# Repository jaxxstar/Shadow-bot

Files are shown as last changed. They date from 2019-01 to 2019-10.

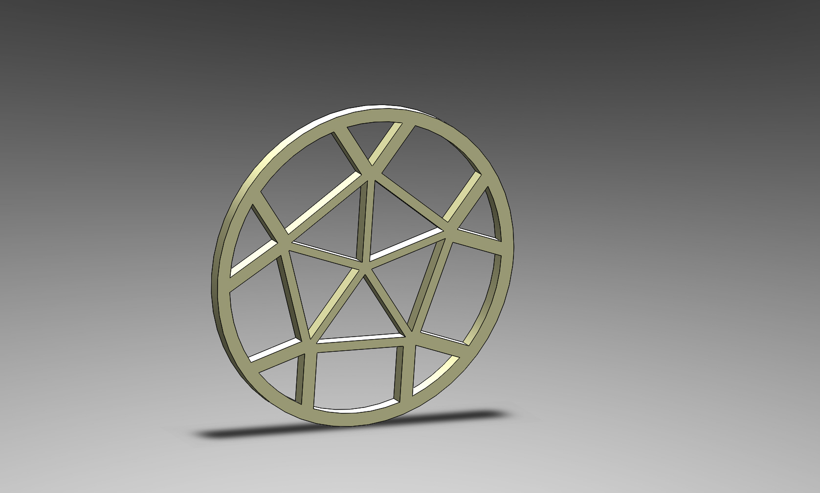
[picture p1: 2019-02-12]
Sangam_Wheel.JPG

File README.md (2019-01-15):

# Shadow Bot

  - Shadow Bot is an all terrain surveillance vehicle(ATV) with a unique capability of transitioning from the ground to the wall .
  - The robot has the ability to move on a wall swiftly and with agility.

# Applications :

> Applications range from monitoring perimeters of highly classified and secured areas such as military bases,airports

> Can be deployed in stealth missions in the army for collecting valuable data such as enemy supplies, enemy location in the army.

> Autonomous robots would save valuable lives in the battlefield simply beacause machines don’t get tired

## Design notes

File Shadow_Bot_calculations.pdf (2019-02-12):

## Shadow Bot Calculations

The governing equations are :
Let the Thrust supplied by the EDF be T, and the Weight off the bot be W, then for No Sliding,

and for No Toppling,

where,
x is the point of application of thrust from the rear wheel of the bot, c is the clearance of the bot with the ground.
For the bot to move ,
Motor torque,M required is ,

where,
R = radius of the wheel.

And also the bot should satisfy these conditions while running,

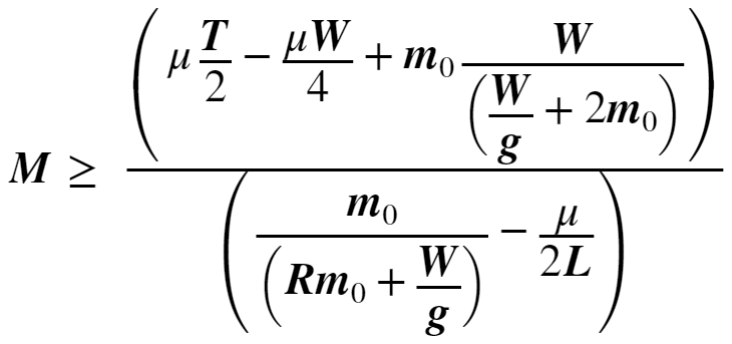
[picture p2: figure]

which has to ensured.
Thrust vs W_max of the bot calculation for different Thrust_distance(x)/clearance of bot ratios keeping other parameters fixed :

% Thrust vs W_max of the bot calculation for different % Thrust_distance(x)/clearance of bot ratios keeping % other parameters fixed
x = table2array(TvsM(13:27,2));
y = table2array(TvsM(13:27,10));
x1 = table2array(TvsM(28:42,2)); y1 = table2array(TvsM(28:42,10)); x2 = table2array(TvsM(43:57,2)); y2 = table2array(TvsM(43:57,10)); x3 = table2array(TvsM(58:72,2)); y3 = table2array(TvsM(58:72,10)); figure;
hold on;
xlabel('Thrust');
ylabel('W-max-toppling');
title('T vs W-max');
plot(x,y,x1,y1,x2,y2,x3,y3);
legend('x/c = 10/8','x/c = 10/7','x/c = 10/6','x/c = 10/5'); grid on;
hold off;

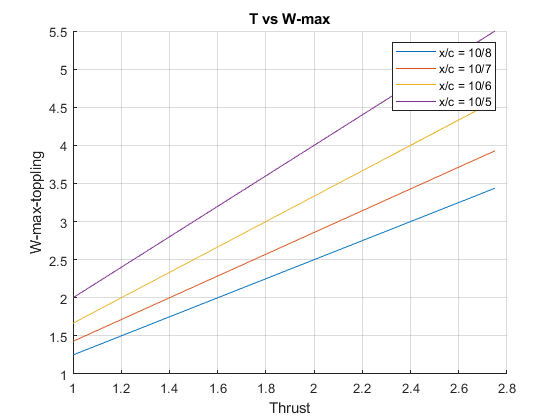
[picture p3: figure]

Motor Torque vs Thrust for the same above conditions :

% Motor Torque vs Thrust for the same above conditions z = table2array(TvsM(13:27,12));

z1 = table2array(TvsM(28:42,12)); z2 = table2array(TvsM(43:57,12)); z3 = table2array(TvsM(58:72,12)); figure;
hold on;
xlabel('Thrust');
ylabel('Motor-Torque-max');
title('T vs Motor-Torque-max'); plot(x,z,x1,z1,x2,z2,x3,z3);
legend('x/c = 10/8','x/c = 10/7','x/c = 10/6','x/c = 10/5'); grid on;
hold off;

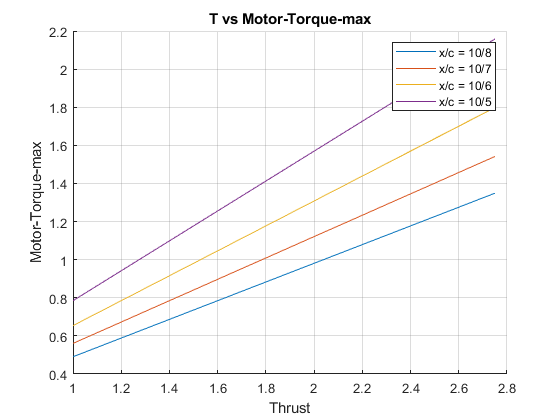
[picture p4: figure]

The Min Motor Torque ,

and | = | and hence depends on µ and T only. It does not depend on other parameters.

Front Wheel Motor Torque:

Calculations for the minimum motor torque required to actuate the front links :

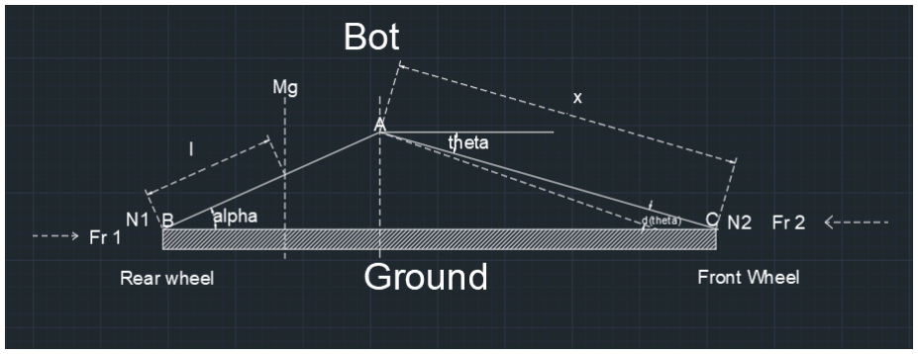
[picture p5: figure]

Analysing the bot using the method of virtual work to obtain the min Motor torque required we get, Le the distance of the center of mass of the bot from the rear wheels be l,
the length of the front links be x.
Let's say that the motor produces a torque, | to actuate the front wheels,
the Work done by the motor to rotate the link by an angle | =

To find Work done by gravity :
Using sine rule in the triangle ABC we get,

let the height of the centre of mass of the bot from the ground be h,

but from (1) we get

but | , where

distance of COM from the back link along the back link

Removing the unknown variable y and relating l and L with the height we get ,

and therefore,

so

Work done by gravity during this time = - | ,

the minus sign indicates that the gravity does negative work.

Work done by the normal reactions | , since there is not net displacement in the vertical direction.

But , frictional force does some work

let the distance of the front wheel from the point of connection of the front links be y then,

Work done by frictional force =

Now using work energy theorem we get ,

Work done by net forces , | but since the system is at rest ,

= 0

and we get ,

- | + ( | ) + | = 0
= | -
and at | we get ,

=

which is the minimum Motor Torque required by the front wheels to be actuated.

Wheel Design :

Euler characteristic ( of Wheel (Disc) is 1.

But,

where,

V is the number of vertices, E is the number of edges,
F is the number of faces.
Let the disc contain P number of Pentagons, H number of Hexagons,
then,

Substituting these values we get,

But we need to find the number of Hexagons,
The number of Hexagons can be arbitrary to fill the remaining space, Here I needded 5 hexagons to cover the fill the disk.
So for our case,

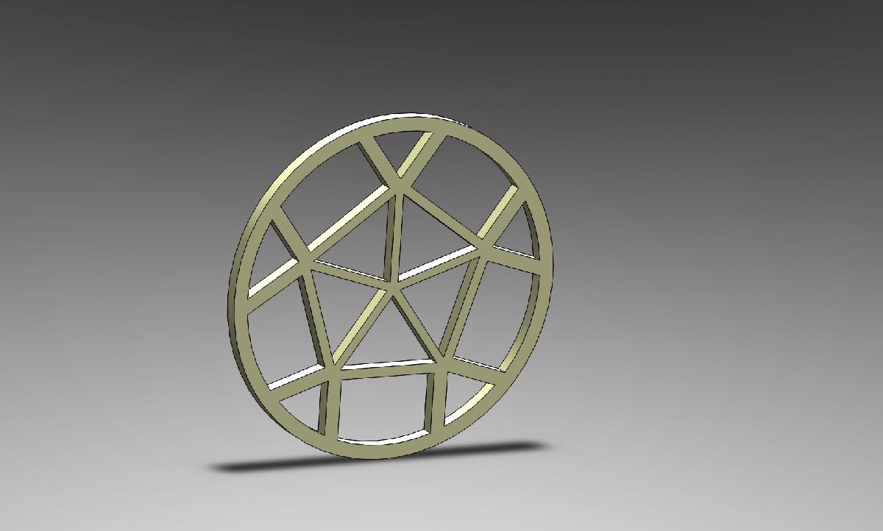
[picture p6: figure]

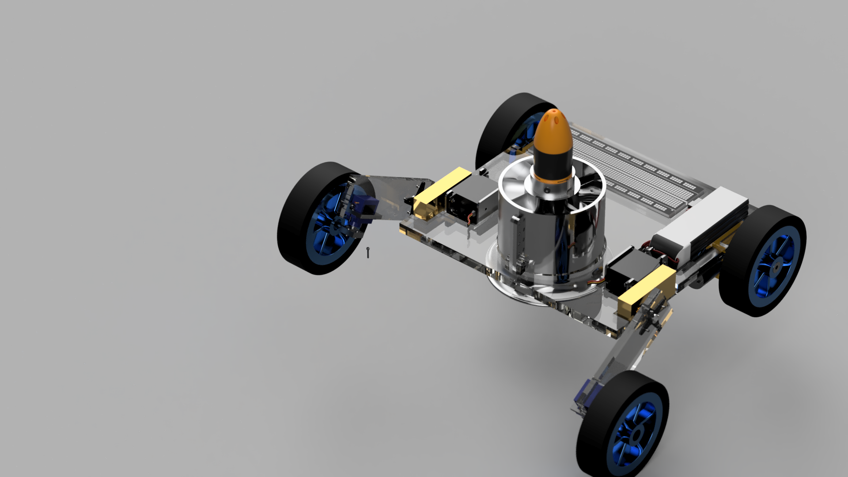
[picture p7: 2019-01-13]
Design Files/new 2.png

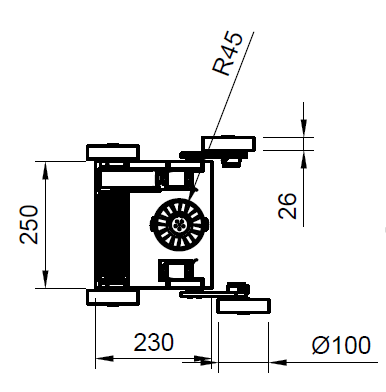
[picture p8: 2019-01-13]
Design Files/Dimensions.png

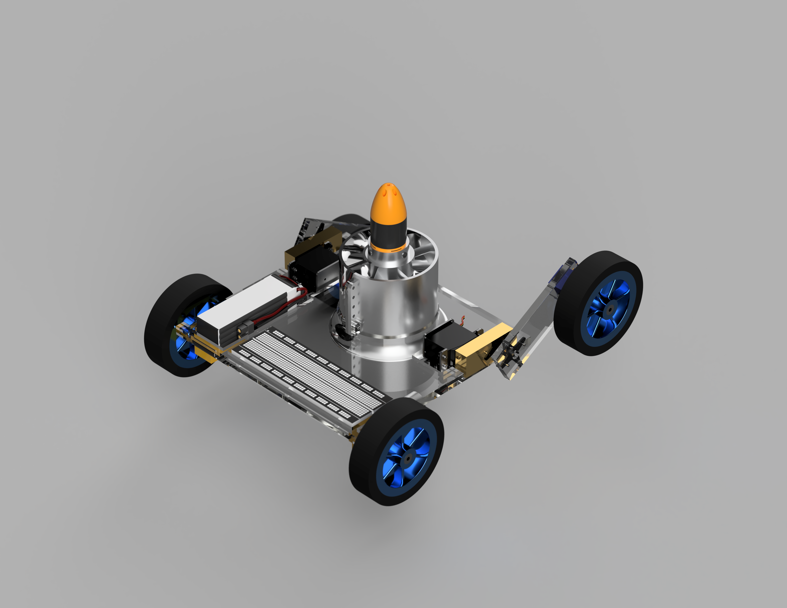
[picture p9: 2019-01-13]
Design Files/new1.png

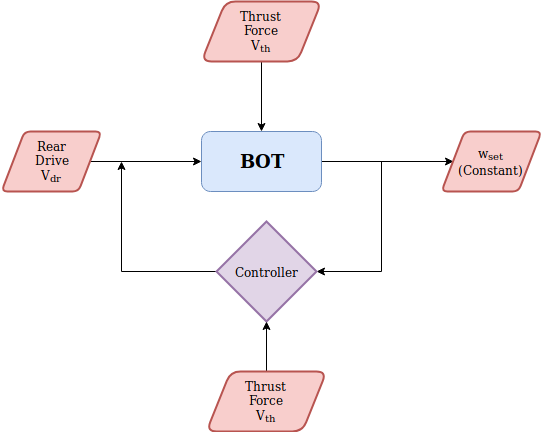
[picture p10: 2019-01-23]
Control_simple.png

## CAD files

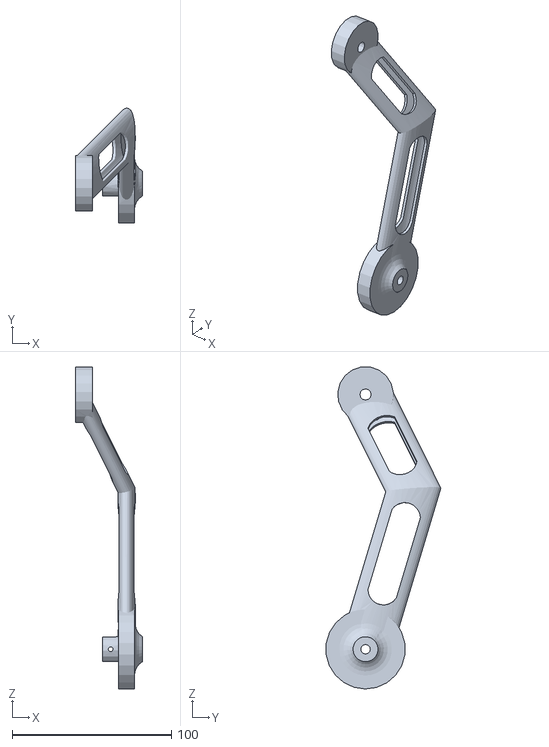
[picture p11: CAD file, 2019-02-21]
Final_design/rightArm.STL
42.0 x 72.1 x 202.3

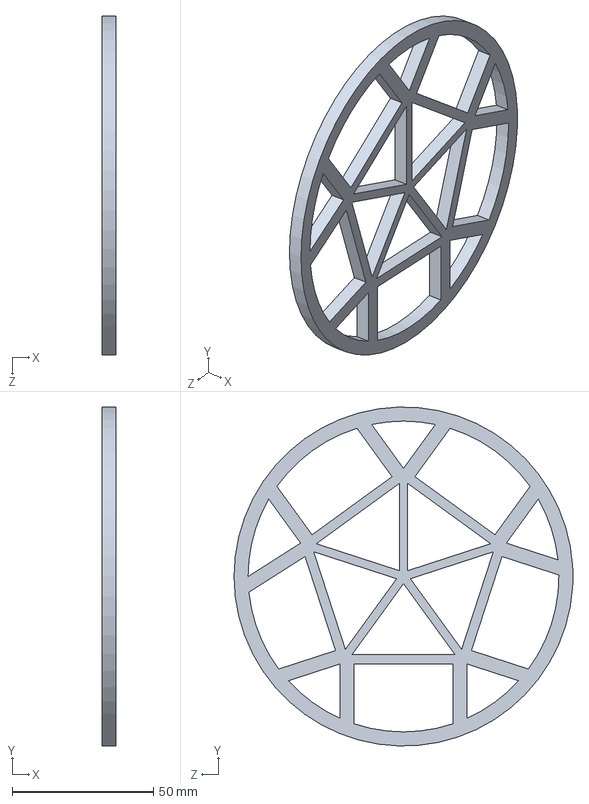
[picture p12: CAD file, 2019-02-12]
Wheel.SLDPRT
5.00 x 119.9 x 120.0 mm

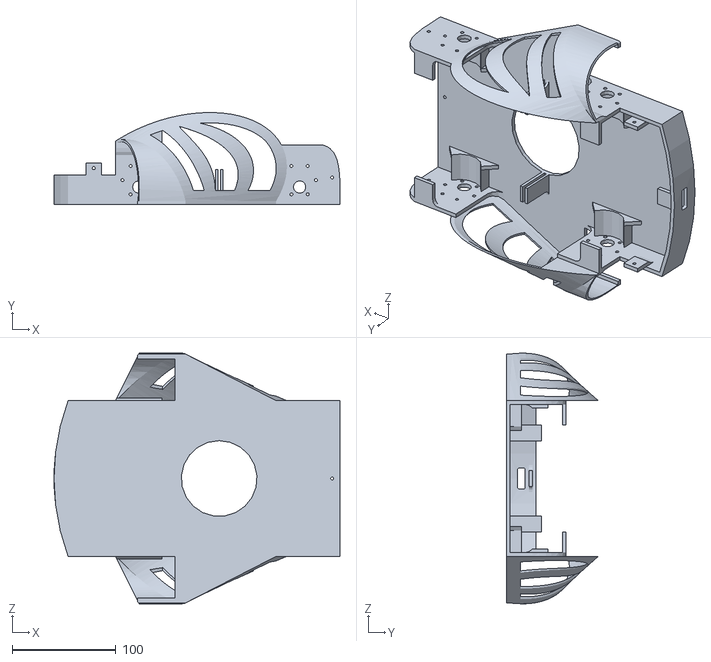
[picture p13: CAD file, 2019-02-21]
Final_design/chassis.STL
275.7 x 88.6 x 241.7

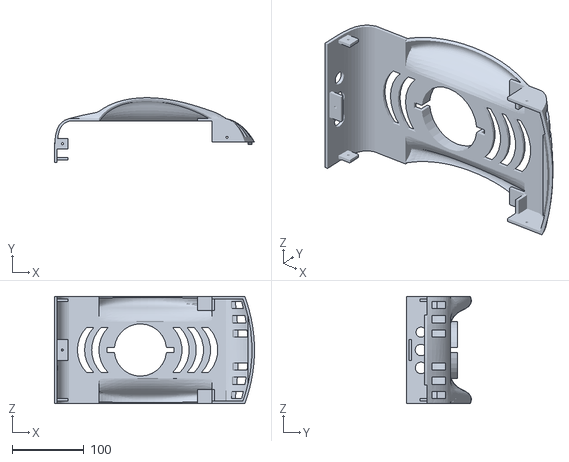
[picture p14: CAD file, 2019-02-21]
Final_design/surfacePlate.STL
279.2 x 90.3 x 150.0

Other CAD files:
Final_design/leftArm.STL

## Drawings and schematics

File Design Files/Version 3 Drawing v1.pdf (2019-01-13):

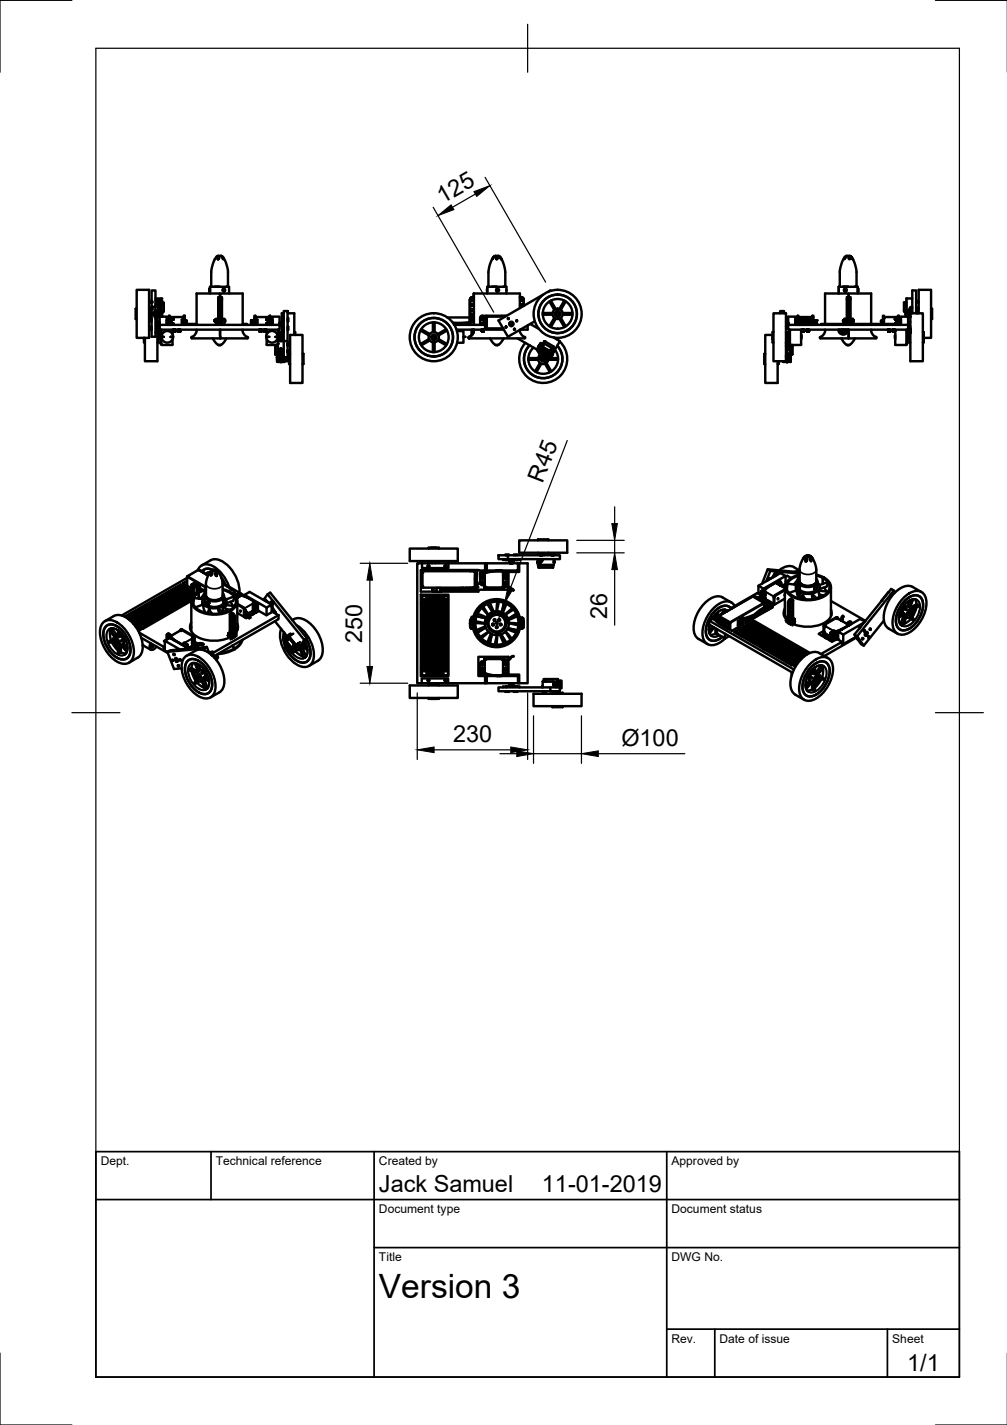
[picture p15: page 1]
Dept.; Technical reference; Created by; Approved by; Document type; Document status; Title; DWG No.; Rev.; Date of issue; Sheet; Version 3; Jack Samuel

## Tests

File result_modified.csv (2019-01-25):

 | Thrust(kg) | x(m) | L(m) | mu | c(m) | m0(kg) | r(m) | W_no_sliding_stationary_min(kg) | W_no_toppling_stationary_max(kg) | Motor_min(kg*m) | Motor_max(kg*m) | stationary_running_match | f<=mu*N
0 | 2.5 | 0.1 | 0.2 | 0.3 | 0.1 | 0.01 | 0.08 | 0.75 | 2.5 | 0.2943 | 0.981 | Yes | Yes
1 | 2.5 | 0.2 | 0.4 | 0.3 | 0.1 | 0.01 | 0.08 | 0.75 | 5 | 0.2943 | 1.962 | Yes | Yes
2 | 2.5 | 0.15 | 0.3 | 0.3 | 0.1 | 0.01 | 0.08 | 0.75 | 3.75 | 0.2943 | 1.4715 | Yes | No
3 | 2.5 | 0.2 | 0.3 | 0.3 | 0.1 | 0.01 | 0.08 | 0.75 | 5 | 0.2943 | 1.962 | Yes | Yes
4 | 2.5 | 0.15 | 0.2 | 0.3 | 0.1 | 0.01 | 0.08 | 0.75 | 3.75 | 0.2943 | 1.4715 | Yes | Yes
5 | 2.5 | 0.1 | 0.15 | 0.3 | 0.1 | 0.01 | 0.08 | 0.75 | 2.5 | 0.2943 | 0.981 | Yes | Yes
6 | 2.5 | 0.2 | 0.4 | 0.3 | 0.08 | 0.1 | 0.08 | 0.75 | 6.25 | 0.2943 | 2.4525 | Yes | No
7 | 2.5 | 0.15 | 0.3 | 0.3 | 0.08 | 0.1 | 0.08 | 0.75 | 4.6875 | 0.2943 | 1.839375 | Yes | No
8 | 2.5 | 0.1 | 0.2 | 0.3 | 0.08 | 0.01 | 0.08 | 0.75 | 3.125 | 0.2943 | 1.22625 | Yes | Yes
9 | 2.5 | 0.2 | 0.3 | 0.3 | 0.08 | 0.01 | 0.08 | 0.75 | 6.25 | 0.2943 | 2.4525 | Yes | Yes
10 | 2.5 | 0.15 | 0.2 | 0.3 | 0.08 | 0.01 | 0.08 | 0.75 | 4.6875 | 0.2943 | 1.839375 | Yes | Yes
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

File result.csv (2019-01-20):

 | Thrust(kg) | x(m) | L(m) | mu | l(m) | m0(kg) | r(m) | min_W(kg) | max_W(kg) | Motor_min | Motor_max
0 | 3.0 | 0.1 | 0.2 | 0.3 | 0.1 | 0.01 | 0.1 | 0.8999999999999999 | 3.0000000000000004 | 0.18154321701810044 | 2.3156417164826237
1 | 3.0 | 0.1 | 0.2 | 0.3 | 0.1 | 0.01 | 0.08 | 0.8999999999999999 | 3.0000000000000004 | 0.18968416845388972 | 2.3427887471565114
2 | 3.0 | 0.2 | 0.4 | 0.3 | 0.2 | 0.01 | 0.1 | 0.8999999999999999 | 3.0000000000000004 | 0.43833750844784874 | 4.8563761879088805
3 | 3.0 | 0.2 | 0.4 | 0.3 | 0.2 | 0.01 | 0.08 | 0.8999999999999999 | 3.0000000000000004 | 0.48901236491580813 | 4.97733200828021
4 | 2.5 | 0.1 | 0.2 | 0.3 | 0.1 | 0.01 | 0.1 | 0.75 | 2.5 | 0.13140004144791367 | 1.924995491885394
5 | 2.5 | 0.1 | 0.2 | 0.3 | 0.1 | 0.01 | 0.08 | 0.75 | 2.5 | 0.1387820662483583 | 1.9523780735622842
6 | 2.5 | 0.2 | 0.4 | 0.3 | 0.2 | 0.01 | 0.1 | 0.75 | 2.5 | 0.33382713232713207 | 4.078816599448101
7 | 2.5 | 0.2 | 0.4 | 0.3 | 0.2 | 0.01 | 0.08 | 0.75 | 2.5 | 0.3859876217532465 | 4.203742069569023
8 | 1.5 | 0.1 | 0.2 | 0.3 | 0.1 | 0.01 | 0.08 | 0.44999999999999996 | 1.5000000000000002 | 0.025429569632495184 | 1.171753689434505
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

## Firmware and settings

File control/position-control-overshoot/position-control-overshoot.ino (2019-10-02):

#include <PID_v1.h>  //Left motor header
//--------------- ENCODER PINS/VARIABLES FOR LEFT -----------------//

#define encoderPinLA 2
#define encoderPinLB 4
int PPR = 4920;  // Encoder Pulse per revolution.
int angle = 360; // Maximum degree of motion.
int left_aState;
int left_counter;

//--------------- ENCODER PINS/VARIABLES FOR RIGHT -----------------//

#define encoderPinRinterrupt 1
#define encoderPinRA 3
#define encoderPinRB 7
//int PPR = 4920;  // Encoder Pulse per revolution.
//int angle = 360; // Maximum degree of motion.
int right_aState;
int right_counter;

//---------------- MOTOR PINS/VARIABLES FOR LEFT ------------------//

#define LEnable 17 //Motor Enamble pin Runs on PWM signal
#define LFwd  19  // Motor Forward pin
#define LRev  18 // Motor Reverse pin
int User_InputL = 30;  // left Positive angle is down
int REVL = 0;
int linkanglel = 0;

//---------------- MOTOR PINS/VARIABLES FOR RIGHT ------------------//

#define REnable 16 //Motor Enamble pin Runs on PWM signal
#define RFwd  14   // Motor Forward pin
#define RRev  15   // Motor Reverse pin
int User_InputR = 0;
int REVR = 0;
int linkangler = 0;

//------------------- PID VARIABLES FOR RIGHT----------------------//
double error = 0;
double angleInp = 0; //make it NEGATIVE
double setpointR = 0;
double thetar = 0;
int overshootflagr = 0;
double errord = 0;
double preverror = 0;
double errori = 0;
double controlinput = 0;
double dt = 0;

//JACK PROOF
double kpr = 500.0, kir = 0, kdr = 0 /10000; // modify for optimal performance
double inputr = 0, outputr = 0, setpointr = 0;


//------------------- PID VARIABLES FOR LEFT ----------------------//
int i = 45;

//IF THE MOTOR DRIVER HEATS UP, THE MOTORS GO CRAZY
//TO BE FINE TUNED

double kpl = 500, kil = 0.0, kdl = 0/10000; // modify for optimal performance
double inputl = 0, outputl = 0, setpointl = 0;
double thetal = 0;
int overshootflagl = 0;

PID myPIDL(&inputl, &outputl, &setpointl, kpl, kil, kdl, DIRECT);

//------------------- MODIFIED DYNAMICS CHART ----------------------//
/* ================================================================= /
 *  SPRING 1 => double kpl = 0.35, kil = 0, kdl = 0 /10000;
 *  SPRING 2 => double kpl = 0.65, kil = 0, kdl = 0 /10000;
 *  DAMPER 1 => double kpl = 0.65, kil = 0, kdl = 2 /10000;
 *  DAMPER 2 => double kpl = 0.65, kil = 0, kdl = 6 /10000;
   ================================================================ */
//------------------------------------------------------------------//

void setup() 
{
  motorSetupL();
  motorSetupR();
  //Serial.begin(9600); //initialize serial comunication
  encoderSetupL();      //Serial communication is messing with the timers and analog pin output
  encoderSetupR();
  

  //--------- Timer setup ----------//
  TCCR1B = TCCR1B & 0b11111000 | 1;
  
  myPIDL.SetMode(AUTOMATIC);          //set PID in Auto mode
  myPIDL.SetSampleTime(1);            //refresh rate of PID controller
  myPIDL.SetOutputLimits(-150, 150);  //this is the MAX PWM value to move motor, here change in value reflect change in speed of motor.
   //--------- Timer setup ----------//
  TCCR1B = TCCR1B & 0b11111000 | 1;
  //analogWrite(REnable,0);
 
}

void loop() 
{
  angleInp = -i;     //right, negative here is downward in bot
  User_InputL = i;   //left, positive here is downward in bot
  
  REVL = remapl(User_InputL);
  setpointl = REVL;
  inputl = left_counter;
  linkanglel = (left_counter*0.073170732); // To print left link angle if reqd.
  linkanglel = linkanglel%360;
 
  
  myPIDL.Compute();
  pwmOutl(outputl);

  setpointR = angleInp;
  thetar = invRemap(right_counter);
  thetal = invRemap(left_counter);
  if (overshootflagl == 1)
  {
    //Serial.println("Left Cutoff");
    finishl();
    delay(100);
  }
  if (overshootflagr == 1)
  {
    //Serial.println("Right Cutoff");
    finishr();
    delay(100);
  }
  error = thetar - setpointR;
  errord = (error -preverror);
  errori += (error);
  controlinput = (kpr*error) + (kdr*errord) + (kir*errori);

  
  if(controlinput > 150)
  {
    controlinput = 150;
  }
  else if( controlinput < -150)
  {
    controlinput = -150;
  }
  if (controlinput>10)
  {
    forwardr();
    analogWrite(REnable,controlinput);
  }
  else if(controlinput < -10)
  {
    reverser();
    analogWrite(REnable,abs(controlinput));
  }
  else 
  {
    finishr();
  }
 
  preverror = error;
}

void motorSetupL()
{
  pinMode(LEnable, OUTPUT);
  pinMode(LFwd, OUTPUT); 
  pinMode(LRev, OUTPUT);
}
void motorSetupR()
{
  pinMode(REnable, OUTPUT);
  pinMode(RFwd, OUTPUT); 
  pinMode(RRev, OUTPUT);
}

void encoderSetupL()
{
  pinMode(encoderPinLA, INPUT_PULLUP); 
  pinMode(encoderPinLB, INPUT_PULLUP);
  digitalWrite(encoderPinLA, HIGH); //turn pullup resistor on
  digitalWrite(encoderPinLB, HIGH); //turn pullup resistor on
  attachInterrupt(0, updateLEncoder, CHANGE); 
}
void encoderSetupR()
{
  pinMode(encoderPinRA, INPUT_PULLUP); 
  pinMode(encoderPinRB, INPUT_PULLUP);
  digitalWrite(encoderPinRA, HIGH); //turn pullup resistor on
  digitalWrite(encoderPinRB, HIGH); //turn pullup resistor on
  attachInterrupt(encoderPinRinterrupt, updateREncoder, CHANGE); 
}

void updateLEncoder()
{
  left_aState = digitalRead(encoderPinLA); 
    
     if(digitalRead(encoderPinLB) != left_aState) 
     { 
       left_counter ++;
     } 
     else 
     {
       left_counter --;
     }
  if(thetal > 95 )
    overshootflagl = 1;
  else if(thetal < -90 )
    overshootflagl = 1;
  else
    overshootflagl = 0;
}

void updateREncoder()
{
  right_aState = digitalRead(encoderPinRA); 
    
     if(digitalRead(encoderPinRB) != right_aState) 
     { 
       right_counter ++;
     } 
     else 
     {
       right_counter --;
     }
  if(thetar > 90 )
    overshootflagr = 1;
  else if(thetar < -95 )
    overshootflagr = 1;     
  else
    overshootflagr = 0;
}

void pwmOutl(int controlinput) 
{
  if(controlinput > 200)
  {
    controlinput = 200;
  }
  else if( controlinput < -200)
  {
    controlinput = -200;
  }
  if (controlinput>10)
  {
    forwardl();
    analogWrite(LEnable,controlinput);
  }
  else if(controlinput < -10)
  {
    reversel();
    analogWrite(LEnable,abs(controlinput));
  }
  else 
  {
    finishl();
  }
  
}

void forwardl () 
{
  digitalWrite(LFwd, HIGH); 
  digitalWrite(LRev, LOW); 
}

void reversel () 
{
  digitalWrite(LFwd, LOW); 
  digitalWrite(LRev, HIGH); 
}

void finishl () 
{
  digitalWrite(LFwd, LOW); 
  digitalWrite(LRev, LOW); 
}
void forwardr () 
{
  digitalWrite(RFwd, HIGH); 
  digitalWrite(RRev, LOW); 
}

void reverser () 
{
  digitalWrite(RFwd, LOW); 
  digitalWrite(RRev, HIGH); 
}

void finishr () 
{
  digitalWrite(RFwd, LOW); 
  digitalWrite(RRev, LOW); 
}

int remapl (int thetal)
{
  int pulsel = floor(13.667 * thetal);
  return pulsel;
}
int remapr (int thetar)
{
  // jack-proof
  int pulser = floor(13.667 * thetar);
  return pulser;
}
int invRemap(int counter)
{
  // jack-proof
  int angle = counter*0.073170732;
  linkangler = (angle%360);
  //Serial.println(linkangler);
  return linkangler;
}

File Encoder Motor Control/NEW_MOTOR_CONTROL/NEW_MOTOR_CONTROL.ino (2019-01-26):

 #include <Arduino.h>

int motorfwd=8;
int motorbwd=9;
//int motorspeed=23;
int motora=11;
int motorb=12;
void setup()
{ Serial.begin(9600);
  Serial.println("hi");
  pinMode(motorfwd,OUTPUT);
 // pinMode(motorspeed,OUTPUT);
  pinMode(motorbwd,OUTPUT);
  pinMode(motora,INPUT);
  pinMode(motorb,INPUT);
 
}
void loop()
{
  //digitalWrite(motorspeed,HIGH);
  digitalWrite(motorfwd,HIGH);
  digitalWrite(motorbwd,LOW);
  Serial.print(digitalRead(motora));
  Serial.print("    ");
  Serial.println(digitalRead(motorb));
  
}

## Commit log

2019-01-13 Motor Specs updated
2019-01-19 Python Code to calculate Parameters added
    [result.csv]
2019-01-20 Calculations pdf removed
    [result.csv]
2019-01-20 modified python code
    [result.csv]
2019-01-20 result.csv added
    [result.csv]
2019-01-25 Calculations interpretation done
    [result_modified.csv]
2019-01-26 Motor Control Update
2019-02-12 Wheel details and calculations for front link torque updated
    [Wheel.SLDPRT]
2019-02-21 Final Design files added
    [chassis.STL, leftArm.STL, rightArm.STL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]
2019-10-02 Added arduino control programs!
    [arduino-config.txt]
